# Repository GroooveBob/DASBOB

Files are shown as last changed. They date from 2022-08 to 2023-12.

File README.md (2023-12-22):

# DASBOB

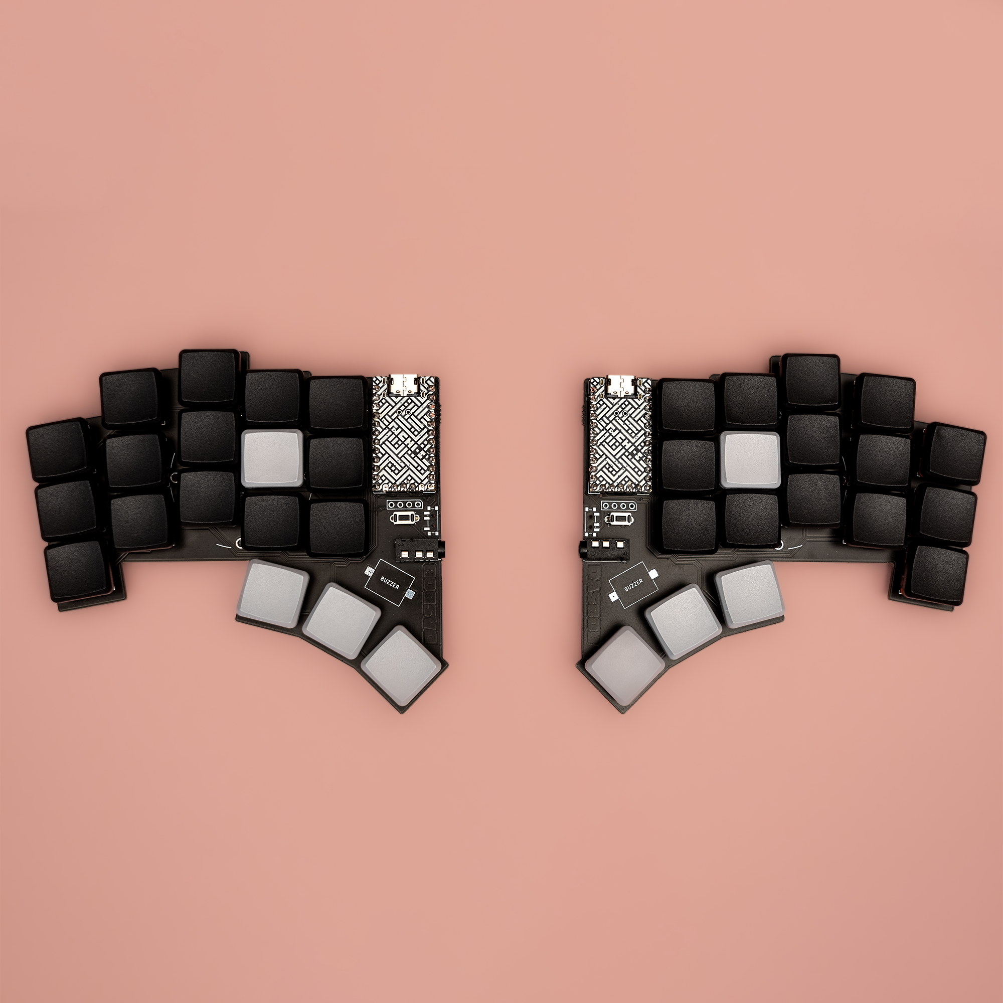
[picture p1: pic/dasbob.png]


36 Key Diodeless Split Choc Keyboard wit a Buzzer 

Firmware:

https://github.com/GroooveBob/DASBOB-qmk

https://codeberg.org/jcowgar/dasbob-36-kmk

https://docs.beekeeb.com/dasbob-keyboard (and layout teste pdf)

Not tested: zmk

special thanks to pcbway for supporting the development



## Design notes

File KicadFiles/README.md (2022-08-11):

# DASBOB
 36 Key Diodeless Split Choc Keyboard

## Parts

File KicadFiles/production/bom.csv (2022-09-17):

Designator | Footprint | Quantity | Value | LCSC Part #
SW12 | Kailh_socket_PG1350_optional | 1 | SW_Push
SW18 | Kailh_socket_PG1350_optional | 1 | SW_Push
SW19 | Kailh_socket_PG1350_optional | 1 | SW_Push
SW15 | Kailh_socket_PG1350_optional | 1 | SW_Push
WWS1 | SW_SPDT_PCM12 | 1 | SW_SPDT
SW23 | Kailh_socket_PG1350_optional | 1 | SW_Push
SW28 | Kailh_socket_PG1350_optional | 1 | SW_Push
JP1 | JUMPER_SMD_2DUB | 1 | BLUETOOTH
SW4 | Kailh_socket_PG1350_optional | 1 | SW_Push
SW17 | Kailh_socket_PG1350_optional | 1 | SW_Push
U3 | I2C_Breakout | 1 | OLED1
U4 | I2C_Breakout | 1 | OLED2
SW16 | Kailh_socket_PG1350_optional | 1 | SW_Push
H6 | SinglePad | 1 | MountingHole_Pad
SW32 | Kailh_socket_PG1350_optional | 1 | SW_Push
J2 | TRRS-PJ-320A | 1 | TRRS LEFT
SW24 | Kailh_socket_PG1350_optional | 1 | SW_Push
SW35 | Kailh_socket_PG1350_optional | 1 | SW_Push
puck2 | Tenting_Pucksmol | 1 | Hole
puck1 | Tenting_Pucksmol | 1 | Hole
SW3 | Kailh_socket_PG1350_optional | 1 | SW_Push
H2 | breakaway-mousebites | 1 | Mousebites
RST1 | SW_ResetSW | 1 | SW_Push
SW22 | Kailh_socket_PG1350_optional | 1 | SW_Push
H3 | SinglePad | 1 | MountingHole_Pad
SWW1 | SW_SPDT_PCM12 | 1 | SW_SPDT
JP2 | JUMPER_SMD_2DUB | 1 | WIRED
SW34 | Kailh_socket_PG1350_optional | 1 | SW_Push
SW20 | Kailh_socket_PG1350_optional | 1 | SW_Push
SW30 | Kailh_socket_PG1350_optional | 1 | SW_Push
SW6 | Kailh_socket_PG1350_optional | 1 | SW_Push
BZ1 | Buzzer_Mallory_AST1109MLTRQ | 1 | Buzzer
SW10 | Kailh_socket_PG1350_optional | 1 | SW_Push
BZ2 | Buzzer_Mallory_AST1109MLTRQ | 1 | Buzzer
SW7 | Kailh_socket_PG1350_optional | 1 | SW_Push
SW27 | Kailh_socket_PG1350_optional | 1 | SW_Push
JP3 | JUMPER_SMD_2DUB | 1 | BLAUZAHN
SW25 | Kailh_socket_PG1350_optional | 1 | SW_Push
SW13 | Kailh_socket_PG1350_optional | 1 | SW_Push
SW29 | Kailh_socket_PG1350_optional | 1 | SW_Push
TSR1 | SW_ResetSW | 1 | SW_Push
H4 | SinglePad | 1 | MountingHole_Pad
SW11 | Kailh_socket_PG1350_optional | 1 | SW_Push
SW1 | Kailh_socket_PG1350_optional | 1 | SW_Push
SW2 | Kailh_socket_PG1350_optional | 1 | SW_Push
H5 | SinglePad | 1 | MountingHole_Pad
H10 | breakaway-mousebites | 1 | Mousebites
SW9 | Kailh_socket_PG1350_optional | 1 | SW_Push
BAT1 | BAT | 1 | Conn_01x02_Male
J1 | TRRS-PJ-320A | 1 | TRRS LEFT
H9 | breakaway-mousebites | 1 | Mousebites
JP4 | JUMPER_SMD_2DUB | 1 | KABEL
SW36 | Kailh_socket_PG1350_optional | 1 | SW_Push
H1 | breakaway-mousebites | 1 | Mousebites
H7 | SinglePad | 1 | MountingHole_Pad
SW5 | Kailh_socket_PG1350_optional | 1 | SW_Push
H12 | Gauge_50mm_Type1_SilkScreenTop | 1 | Ruler
TAB1 | BAT | 1 | Conn_01x02_Male
SW33 | Kailh_socket_PG1350_optional | 1 | SW_Push
SW14 | Kailh_socket_PG1350_optional | 1 | SW_Push
SW31 | Kailh_socket_PG1350_optional | 1 | SW_Push
H11 | MountingHole_2.7mm_M2.5_DIN965 | 1 | M3 MountingHole
SW8 | Kailh_socket_PG1350_optional | 1 | SW_Push
SW26 | Kailh_socket_PG1350_optional | 1 | SW_Push
H8 | SinglePad | 1 | MountingHole_Pad
SW21 | Kailh_socket_PG1350_optional | 1 | SW_Push
U1 | Elite-C | 1 | Elite-C RIGHT
U2 | Elite-C | 1 | Elite-C LEFT

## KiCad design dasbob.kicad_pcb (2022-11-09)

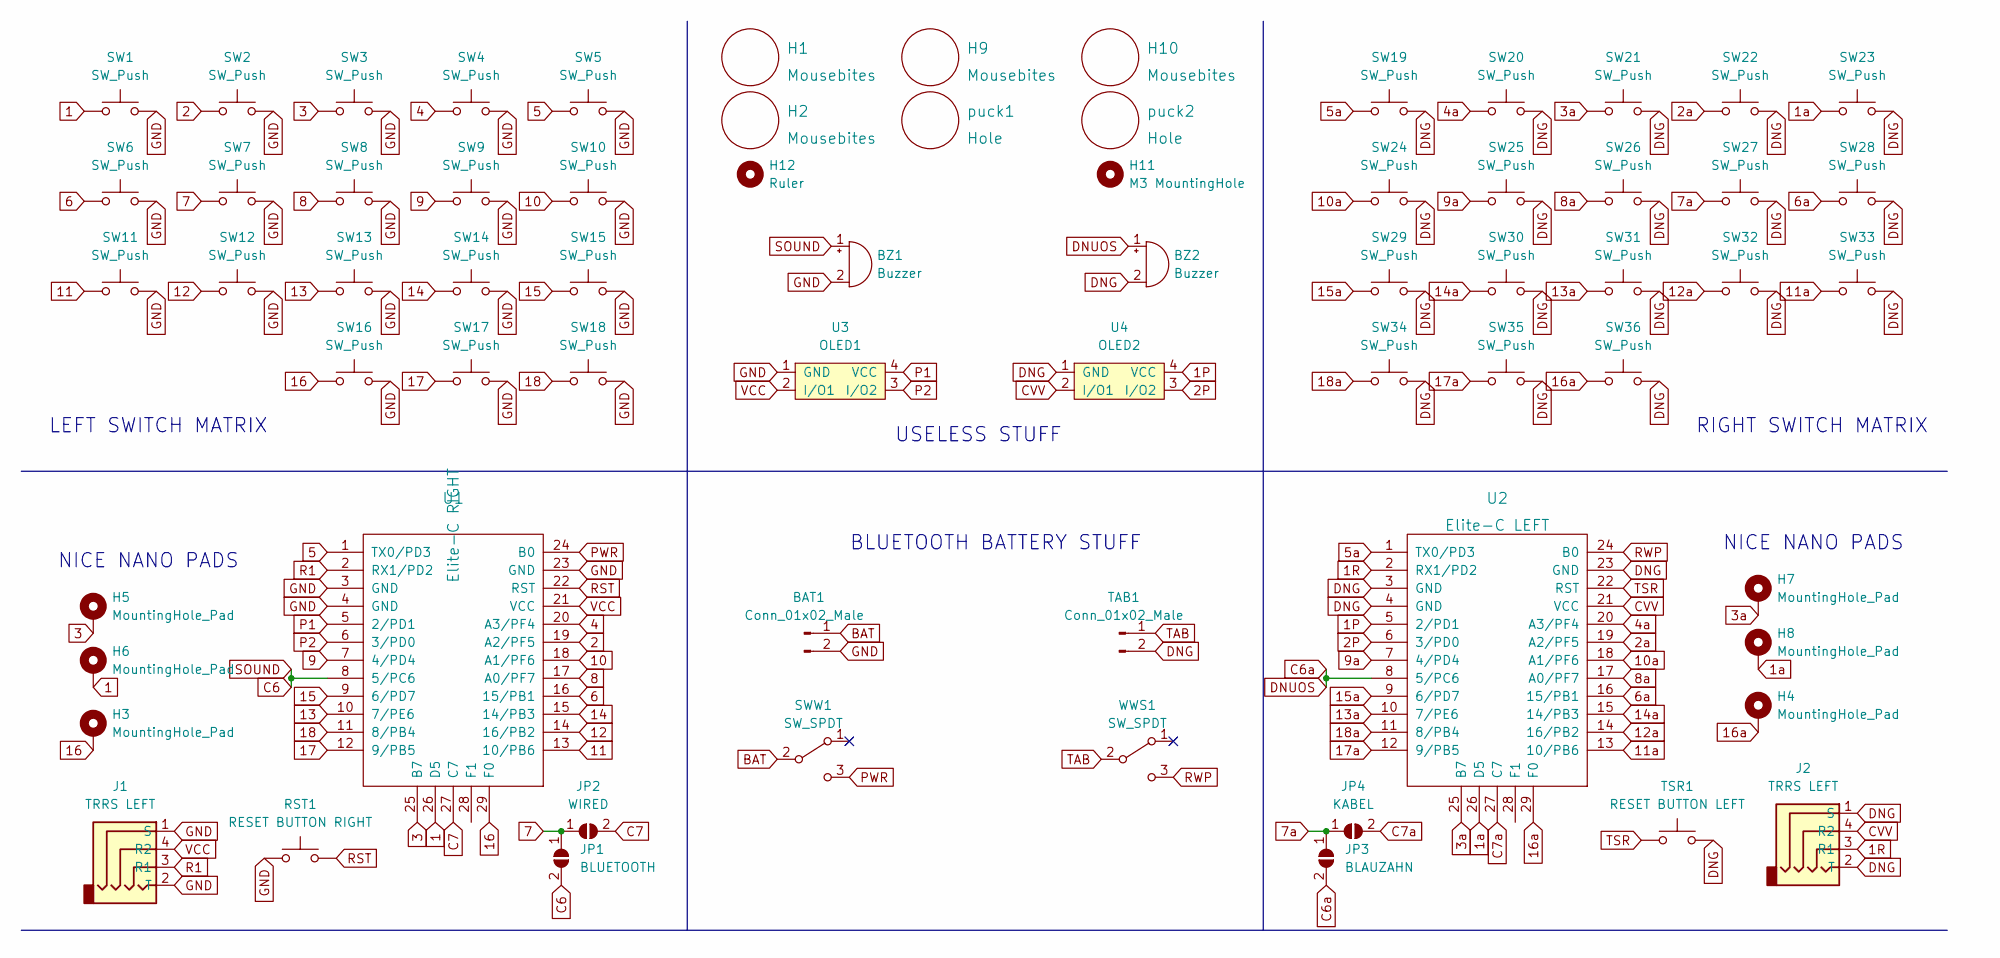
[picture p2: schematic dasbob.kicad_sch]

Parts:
BAT1: Conn_01x02_Male; BAT
BZ1, BZ2: Buzzer; Buzzer_Mallory_AST1109MLTRQ
H1, H2, H9, H10: Mousebites; breakaway-mousebites
H3, H4, H5, H6, H7, H8: MountingHole_Pad; SinglePad
H11: M3 MountingHole; MountingHole_2.7mm_M2.5_DIN965
H12: Ruler; Gauge_50mm_Type1_SilkScreenTop
J1, J2: TRRS LEFT; TRRS-PJ-320A
JP1: BLUETOOTH; JUMPER_SMD_2DUB
JP2: WIRED; JUMPER_SMD_2DUB
JP3: BLAUZAHN; JUMPER_SMD_2DUB
JP4: KABEL; JUMPER_SMD_2DUB
RST1: RESET BUTTON RIGHT; ResetSW
SW1, SW2, SW3, SW4, SW5, SW6, SW7, SW8, SW9, SW10, SW11, SW12, SW13, SW14, SW15, SW16, SW17, SW18, SW19, SW20, SW21, SW22, SW23, SW24, SW25, SW26, SW27, SW28, SW29, SW30, SW31, SW32, SW33, SW34, SW35, SW36: SW_Push; Kailh_socket_PG1350_optional
SWW1: SW_SPDT; SW_SPDT_PCM12
TAB1: Conn_01x02_Male; BAT
TSR1: RESET BUTTON LEFT; ResetSW
U1: Elite-C RIGHT; Elite-C
U2: Elite-C LEFT; Elite-C
U3: OLED1; I2C_Breakout
U4: OLED2; I2C_Breakout
WWS1: SW_SPDT; SW_SPDT_PCM12
puck1, puck2: Hole; Tenting_Puck

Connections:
1: H6.1, SW1.1, U1.26 (D5)
1P: U2.5 (2/PD1), U4.4 (VCC)
1R: J2.3 (R1), U2.2 (RX1/PD2)
1a: H8.1, SW23.1, U2.26 (D5)
2: SW2.1, U1.19 (A2/PF5)
2P: U2.6 (3/PD0), U4.3 (I/O2)
2a: SW22.1, U2.19 (A2/PF5)
3: H5.1, SW3.1, U1.25 (B7)
3a: H7.1, SW21.1, U2.25 (B7)
4: SW4.1, U1.20 (A3/PF4)
4a: SW20.1, U2.20 (A3/PF4)
5: SW5.1, U1.1 (TX0/PD3)
5a: SW19.1, U2.1 (TX0/PD3)
6: SW6.1, U1.16 (15/PB1)
6a: SW28.1, U2.16 (15/PB1)
7: JP1.1 (A), JP2.1 (A), SW7.1
7a: JP3.1 (A), JP4.1 (A), SW27.1
8: SW8.1, U1.17 (A0/PF7)
8a: SW26.1, U2.17 (A0/PF7)
9: SW9.1, U1.7 (4/PD4)
9a: SW25.1, U2.7 (4/PD4)
10: SW10.1, U1.18 (A1/PF6)
10a: SW24.1, U2.18 (A1/PF6)
11: SW11.1, U1.13 (10/PB6)
11a: SW33.1, U2.13 (10/PB6)
12: SW12.1, U1.14 (16/PB2)
12a: SW32.1, U2.14 (16/PB2)
13: SW13.1, U1.10 (7/PE6)
13a: SW31.1, U2.10 (7/PE6)
14: SW14.1, U1.15 (14/PB3)
14a: SW30.1, U2.15 (14/PB3)
15: SW15.1, U1.9 (6/PD7)
15a: SW29.1, U2.9 (6/PD7)
16: H3.1, SW16.1, U1.29 (F0)
16a: H4.1, SW36.1, U2.29 (F0)
17: SW17.1, U1.12 (9/PB5)
17a: SW35.1, U2.12 (9/PB5)
18: SW18.1, U1.11 (8/PB4)
18a: SW34.1, U2.11 (8/PB4)
BAT: BAT1.1, SWW1.2 (B)
C7: JP2.2 (B), U1.27 (C7)
C7a: JP4.2 (B), U2.27 (C7)
CVV: J2.4 (R2), U2.21 (VCC), U4.2 (I/O1)
DNG: BZ2.2 (+), J2.1 (S), J2.2 (T), SW19.2, SW20.2, SW21.2, SW22.2, SW23.2, SW24.2, SW25.2, SW26.2, SW27.2, SW28.2, SW29.2, SW30.2, SW31.2, SW32.2, SW33.2, SW34.2, SW35.2, SW36.2, TAB1.2, TSR1.2, U2.3 (GND), U2.4 (GND), U2.23 (GND), U4.1 (GND)
DNUOS: BZ2.1 (-), JP3.2 (B), U2.8 (5/PC6)
GND: BAT1.2, BZ1.2 (+), J1.1 (S), J1.2 (T), RST1.1, SW1.2, SW2.2, SW3.2, SW4.2, SW5.2, SW6.2, SW7.2, SW8.2, SW9.2, SW10.2, SW11.2, SW12.2, SW13.2, SW14.2, SW15.2, SW16.2, SW17.2, SW18.2, U1.3 (GND), U1.4 (GND), U1.23 (GND), U3.1 (GND)
P1: U1.5 (2/PD1), U3.4 (VCC)
P2: U1.6 (3/PD0), U3.3 (I/O2)
PWR: SWW1.3 (C), U1.24 (B0)
R1: J1.3 (R1), U1.2 (RX1/PD2)
RST: RST1.2, U1.22 (RST)
RWP: U2.24 (B0), WWS1.3 (C)
SOUND: BZ1.1 (-), JP1.2 (B), U1.8 (5/PC6)
TAB: TAB1.1, WWS1.2 (B)
TSR: TSR1.1, U2.22 (RST)
VCC: J1.4 (R2), U1.21 (VCC), U3.2 (I/O1)

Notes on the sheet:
RIGHT SWITCH MATRIX
NICE NANO PADS
USELESS STUFF
LEFT SWITCH MATRIX
BLUETOOTH BATTERY STUFF

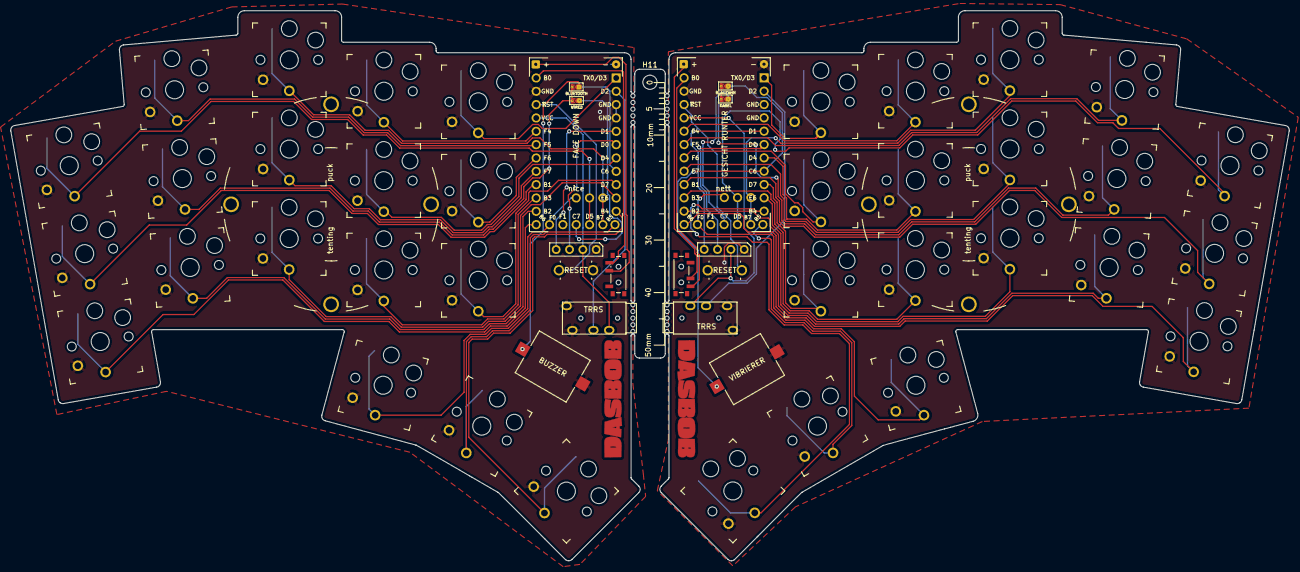
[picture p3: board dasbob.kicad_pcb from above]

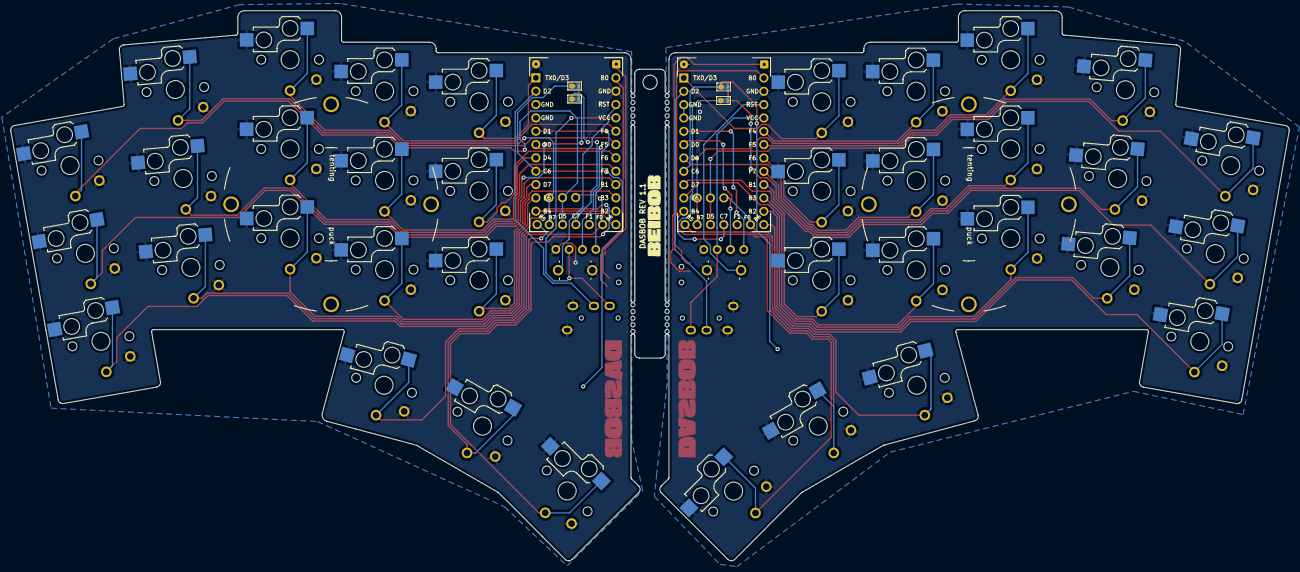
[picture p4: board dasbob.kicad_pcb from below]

Board: 2 copper layers, 243.5 x 104.8 mm, 68 parts (2 on the bottom side), 56 nets.

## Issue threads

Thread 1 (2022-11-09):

Traces shorting 3a and 7a/DNUOS

nwhelan, 2022-11-09:
Thanks for sharing your design! Looking forward to using it. Let me preface this by saying that this is the first time I've had open-source PCBs made, so I'm _certainly_ not ruling out error on my part.

I had these made by JLCPCB and, for whatever reason, I'm having issues with certain pins across all 5 PCBs. Given the consistency of the issue, I'm wondering if two or more traces are too close together. Specifically, I'm having issues with traces 3a and 7a/DNUOS (I'm using a nice!nano v2). Using an ohmmeter, I can bridge the two corresponding pins.

I may try digging out the traces and hand wiring since it only seems to be the two switches which are impacted.

GroooveBob, 2022-11-09:
hello, im not sure wich version of the pcb you are using im still working and updating that thing because im not fully satisfied ... do you maybe still have the geber file so i can check that out?

nwhelan, 2022-11-11:
[gerber.zip](https://github.com/GroooveBob/DASBOB/files/9993639/gerber.zip)
Hey there - thanks for the quick reply. Sorry for the delay. Here are the gerber files I used. Pulled as of 11/2 (US). Thanks again for sharing this! In the meantime, I'm just nipping the problematic traces and wiring those switches directly.

GroooveBob, 2022-11-12:
thanks ... did you used the solder jumper under the mcu?

nwhelan, 2022-11-12:
Yes, connected BLUETOOTH jumper to connect traces 7/SOUND and 7a/DNUOS.

Do both sides of the board need to have the jumper soldered? I connected that jumper on both sides. From the kicad it seemed like there was no harm in soldering both.

GroooveBob, 2022-11-13:
i found the issue on the gerber ... i did not update the groundfill :(

nwhelan, 2022-11-14:
Ah! I was actually able to isolate the impacted traces still and wire those switches directly without too much fuss. All's well that ends well. I'm up and running with it on ZMK.

Closed 2022-11-20.

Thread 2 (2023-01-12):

Plate for hotswap

patrick-elmquist, 2023-01-12:
Really like the design and tempted to order a set of PCBs, just curious if you wanna make it hotswappable, don't you need a plate to keep the switches in place?

GroooveBob, 2023-01-12:
no you dont need a plate the holes are tight ... tested for month :D

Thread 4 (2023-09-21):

Firmware for ZMK

rudrar, 2023-09-21:
I am really interested to Build this Keeb. It would be great if you can make ZMK firmware since I use wireless keeb. Can you please make a ZMK firmware for this keeb?

AbrahamAlcaina, 2024-05-03:
Hi, any news on this topic.
It will be possible to use nice!nano controller?

GroooveBob, 2024-05-04:
https://github.com/rudrar/zmk-config-dasbob there is a zmk config for dasbob

AbrahamAlcaina, 2024-05-04:
@GroooveBob thank you for your support.

cervalx, 2024-08-07:
Hi everyone, I am using ZMK as a firmware and Bluetooth setup on both sides, does anyone have a

AbrahamAlcaina, 2024-08-07:
In my case I click on the reset and works again

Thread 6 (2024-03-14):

Are the labels for the buzzer on the PCB backward?

twalker, 2024-03-14:
Thank you for this creating and releasing this PCB. The thumb clusters located excellently for my hands. I could not help but add a piezo buzzer for the fun of it and oriented the "+" label of the buzzer with the "+" labeled on the PCB--the right pad. The buzzers made no sound until I reversed the orientation. Is the PCB mislabeled?

Also, the right side does not work with audio enabled and both halves are connected. Does a `AUDIO_PIN_ALT` need to be defined? Do you think that may be the root cause of my issue?

Thanks again for a great layout and PCB design.

"+" on Buzzer appears to go to the "+" printed on the PCB:
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

Built with incorrect orientation of buzzer:
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

GroooveBob, 2024-03-14:
ahhh sorry the + is not a label its the conection to die GND-plane ... the buzzer is only working on one side gmk only supports on side :(

twalker, 2024-03-15:
I see. Thanks for the explanation.

Closed 2024-03-15.

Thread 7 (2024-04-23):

key rollover

arialdomartini, 2024-04-23:
Hello!
That's not an issue, it's more a request to provide more information about the key rollover.
Being diodeless, I assume DASBOB must have some limitations due to ghosting, but I was not able to find any information about that.
The layout I would like to use has some combinations with 3 keys on one part and 2 on the other one.

Thank you!

GroooveBob, 2024-05-04:
every key has a own pin i dont think there is any limitation

arialdomartini, 2024-05-22:
I built a couple of DASBOB and can confirm it has a perfect n-key rollover. AMAZING.
Closing this issue!

Closed 2024-05-22.

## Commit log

2022-08-11 here we go
    [dasbob.kicad_pcb, dasbob.kicad_sch]
2022-08-12 moved thumbs 1mm down
    [dasbob.kicad_pcb]
2022-08-14 routed the oled to the wrong pins because im a ducking idiot now i fixed it
    [dasbob.kicad_pcb, dasbob.kicad_sch]
2022-09-17 buzzer was not working
    buzzer was not working put a jumper for it on the board
    [bom.csv, dasbob.kicad_pcb, dasbob.kicad_sch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]
2022-11-09 ground issues
    [dasbob.kicad_pcb, dasbob.kicad_sch]
